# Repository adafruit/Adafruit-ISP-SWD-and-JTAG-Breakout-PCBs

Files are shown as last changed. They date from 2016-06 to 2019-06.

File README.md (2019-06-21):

## Adafruit SWD and JTAG Breakout PCBs

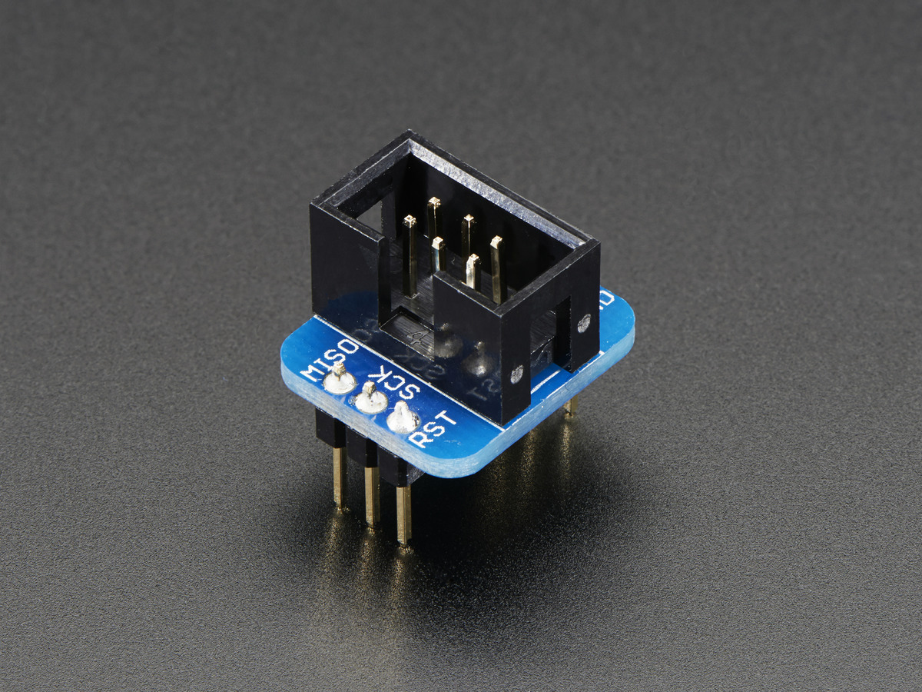
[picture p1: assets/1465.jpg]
<a href="http://www.adafruit.com/products/1465">&nbsp; 
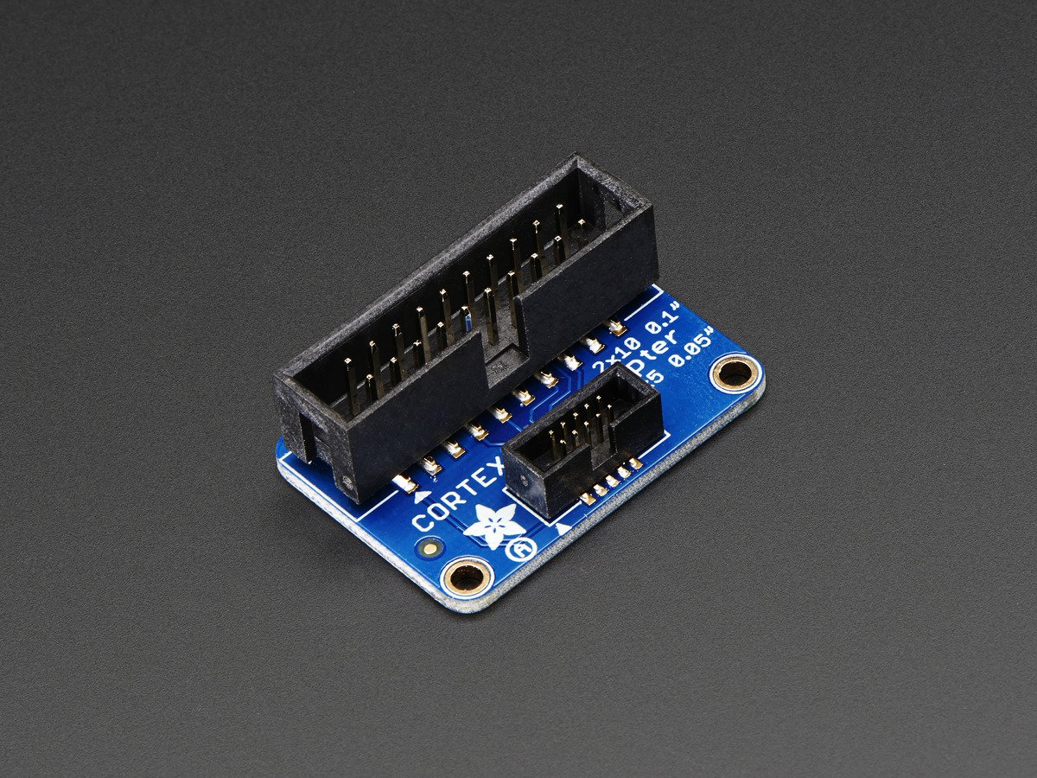
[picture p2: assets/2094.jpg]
<a href="http://www.adafruit.com/products/2094">&nbsp; 
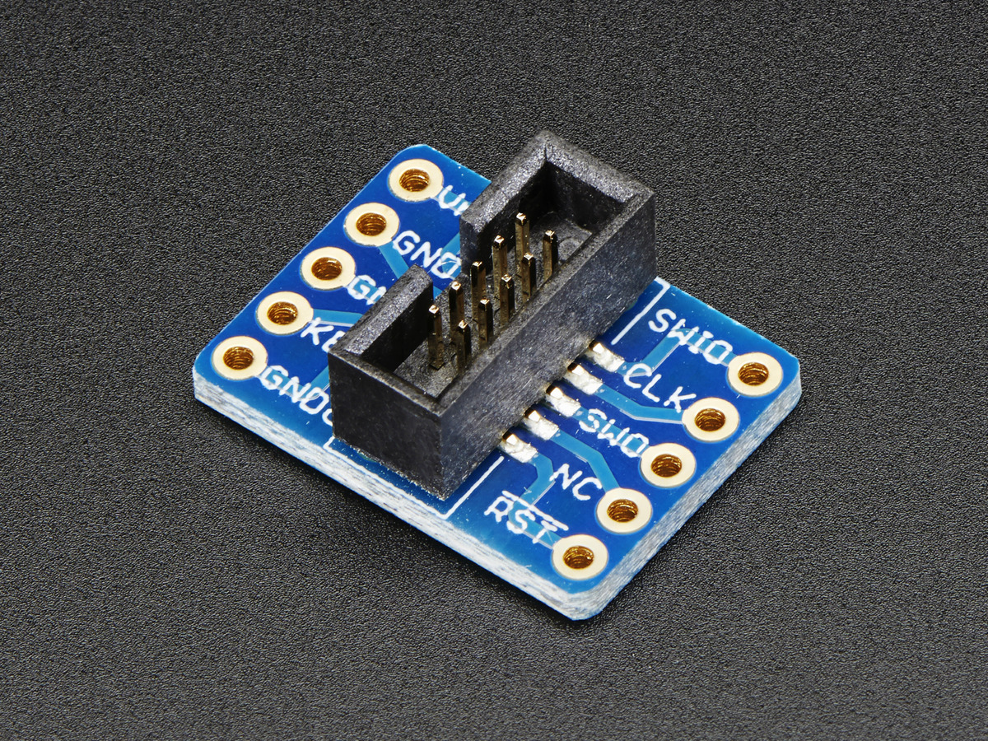
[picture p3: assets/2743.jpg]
<a href="http://www.adafruit.com/products/2743"><br/>
Click an image to purchase from the Adafruit shop</a>

PCB files for the Adafruit ISP, SWD and JTAG Breakouts. Format is EagleCAD schematic and board layout

For more details, check out the product pages at
* https://www.adafruit.com/products/1465 (AVR ISP)
* https://www.adafruit.com/products/2094 (JTAG to SWD)
* https://www.adafruit.com/products/2743 (SWD breakout)

### Descriptions

**AVR ISP:** It's rare to find a mini kit so elegant, it deserves its own Haiku. A simple breakout, 2x3 box header in the center, two 1x3's on the side. Plugs into any breadboard for neat wiring (in both nifty and clean senses of the word).

Comes with a quality mini PCB, a 2x3 box header and a small stick of 0.1" header. Requires some light soldering to use: plug the 2x3 in on the top and solder all six pins, then break the header in half and put each half into a breadboard to hold them steady. Place the breakout on top and solder the side pins. Will last you years and years.

**JTAG to SWD:** This adapter board is designed for adapting a 'classic' 2x10 (0.1"/2.54mm pitch) JTAG cable to a slimmer 2x5 (0.05"/1.27mm pitch) SWD Cable.  It's helpful for using products like the JTAGulator or SEGGER J-Link with tiny boards that use the 10-pin SWD programming connector.

This board comes with no cables.  It's really just the adapter - but is super helpful when you want to use JTAG debugging on boards that can't support 2x10 cables.

**SWD Breakout:** This adapter board is designed to make it easier to use ARM dev boards that use slimmer 2x5 (0.05"/1.27mm pitch) SWD cables for programming.  It's helpful for using products like the JTAGulator, STLink or SEGGER J-Link with tiny boards that use the 10-pin SWD programming connector, often Cortex M0 or M3's.

### License

Adafruit invests time and resources providing this open source design, please support Adafruit and open-source hardware by purchasing products from [Adafruit](https://www.adafruit.com)!

Designed by Limor Fried/Ladyada for Adafruit Industries.

Creative Commons Attribution/Share-Alike, all text above must be included in any redistribution. See license.txt for additional details.

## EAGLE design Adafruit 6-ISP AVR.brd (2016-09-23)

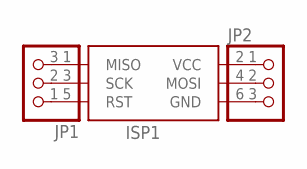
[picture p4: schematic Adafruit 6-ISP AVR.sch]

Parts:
ISP1: AVRISP-BOX
JP1, JP2: PINHD-1X3CB; 1X03-CLEANBIG

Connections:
GND: ISP1.6 (GND), JP2.3
MISO: ISP1.1 (MISO), JP1.3
MOSI: ISP1.4 (MOSI), JP2.2
RST: ISP1.5 (RST), JP1.1
SCK: ISP1.3 (SCK), JP1.2
VCC: ISP1.2 (VCC), JP2.1

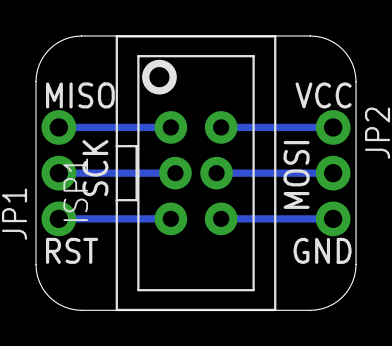
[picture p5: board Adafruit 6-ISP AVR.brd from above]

Board: 2 copper layers, 17.8 x 15.2 mm, 4 parts (1 on the bottom side), 6 nets.

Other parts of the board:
U$1: ADAFRUIT_3.5MM

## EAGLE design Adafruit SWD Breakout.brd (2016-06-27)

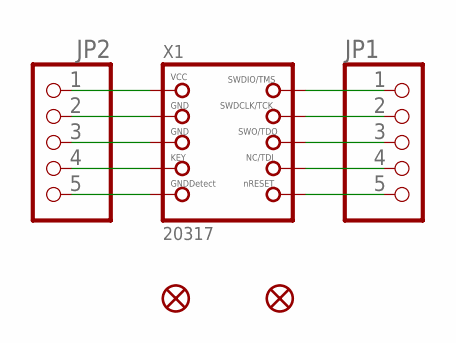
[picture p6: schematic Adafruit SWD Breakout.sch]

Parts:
FID1, FID2: FIDUCIAL""; FIDUCIAL_1MM
JP1, JP2: HEADER-1X576MIL_FULL; 1X05_ROUND_FULL_76
X1: 20317; 2X05_1.27MM_BOX_POSTS

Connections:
unnamed: JP2.1, X1.1 (VCC)
unnamed: JP2.2, X1.3 (GND)
unnamed: JP2.3, X1.5 (GND)
unnamed: JP2.4, X1.7 (KEY)
unnamed: JP2.5, X1.9 (GNDDETECT)
unnamed: JP1.1, X1.2 (SWDIO)
unnamed: JP1.2, X1.4 (SWDCLK)
unnamed: JP1.3, X1.6 (SWO)
unnamed: JP1.4, X1.8 (TDI)
unnamed: JP1.5, X1.10 (NRESET)

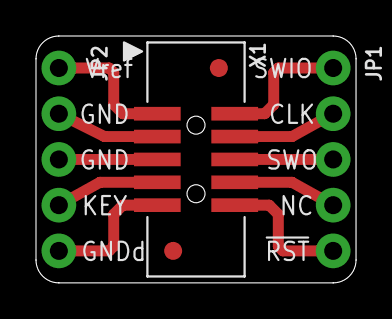
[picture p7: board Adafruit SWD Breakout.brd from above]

Board: 2 copper layers, 17.8 x 13.7 mm, 6 parts (1 on the bottom side), 10 nets.

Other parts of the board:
U$2: ADAFRUIT_2.5MM

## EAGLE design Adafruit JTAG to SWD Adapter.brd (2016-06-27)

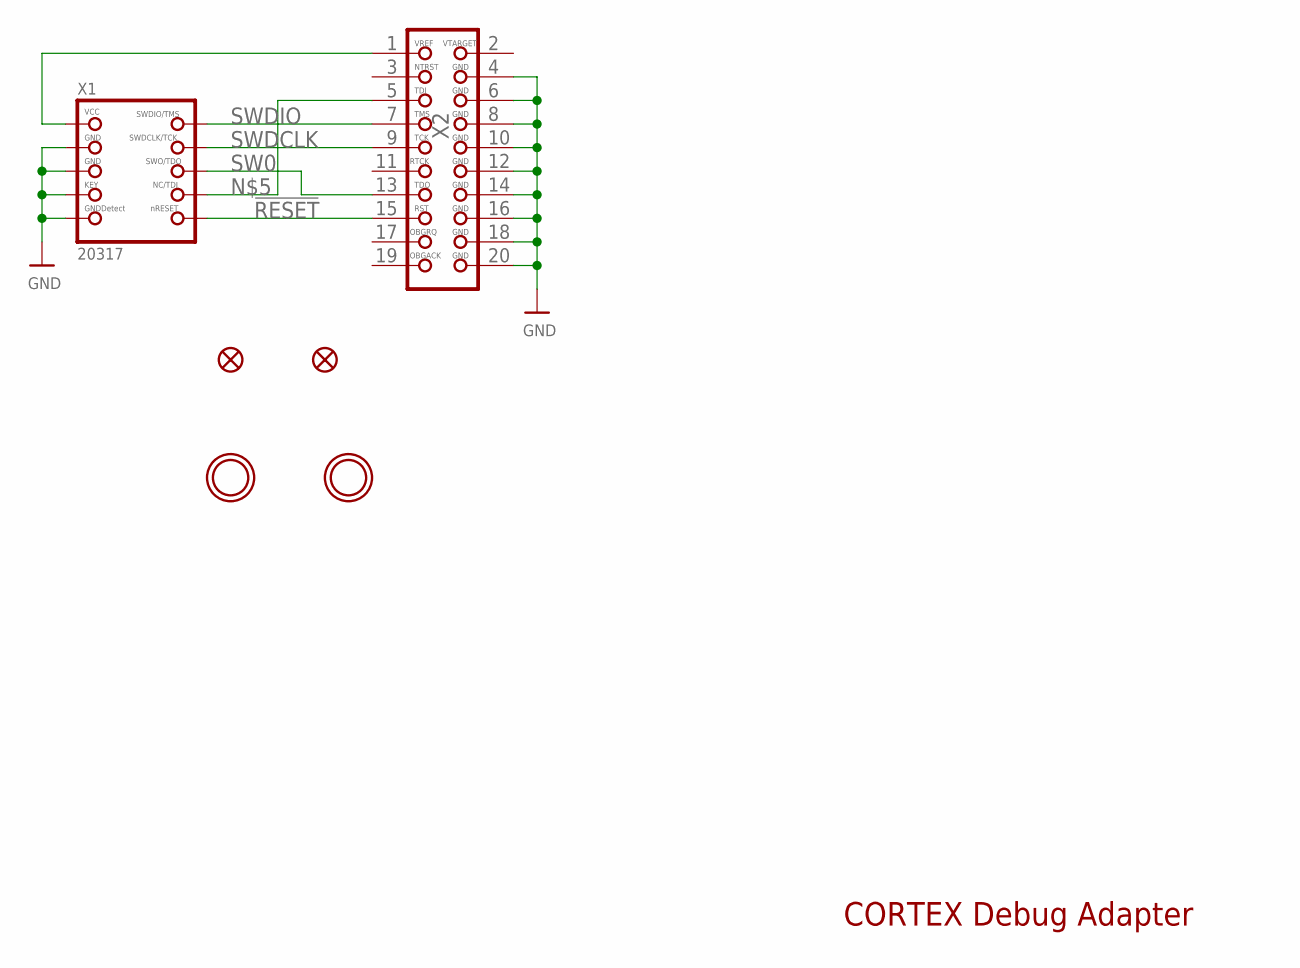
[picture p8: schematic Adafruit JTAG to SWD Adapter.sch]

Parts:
FID1, FID2: FIDUCIAL""; FIDUCIAL_1MM
U$5, U$6: MOUNTINGHOLE2.5; MOUNTINGHOLE_2.5_PLATED
X1: 20317; 2X05_1.27MM_BOX_POSTS
X2: 03587; 2X10_SMT_FEMALE

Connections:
!RESET: X1.10 (NRESET), X2.15
GND: X1.3 (GND), X1.5 (GND), X1.7 (KEY), X1.9 (GNDDETECT), X2.4, X2.6, X2.8, X2.10, X2.12, X2.14, X2.16, X2.18, X2.20
unnamed: X1.8 (TDI), X2.5
SW0: X1.6 (SWO), X2.13
SWDCLK: X1.4 (SWDCLK), X2.9
SWDIO: X1.2 (SWDIO), X2.7
VCC: X1.1 (VCC), X2.1

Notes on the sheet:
CORTEX Debug Adapter

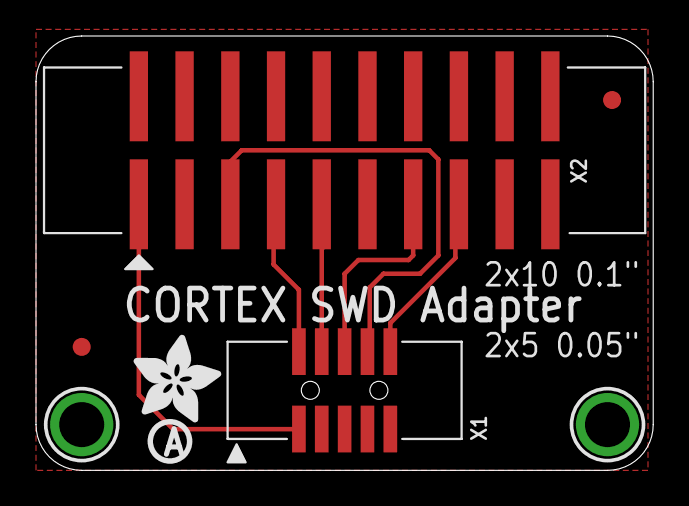
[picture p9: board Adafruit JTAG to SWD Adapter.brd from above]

Board: 2 copper layers, 34.3 x 24.1 mm, 8 parts (0 on the bottom side), 7 nets.

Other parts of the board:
U$3: ADAFRUIT_5MM
U$4: PCBFEAT-REV-056

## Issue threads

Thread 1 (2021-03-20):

JTAG to SWD enhancement proposal

thomas6g, 2021-03-20:
Hello Adafruit,

I'm using the RaspberryPi Pico with a Segger JLink debugger. The Jlink comes with a [virtual com port functionality](https://wiki.segger.com/Using_J-Link_VCOM_functionality). Hence it would be cool if you could rework the JTAG to SWD adapter, that one of the unused PIN of the SWD connector is connected to PIN 17 of the JTAG adapter.

That would offer the possibility to connect the debugger and the serial console with one wire.

Best regards,

Tom

Closed 2021-03-20.

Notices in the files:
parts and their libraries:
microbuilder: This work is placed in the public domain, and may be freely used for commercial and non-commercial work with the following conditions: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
